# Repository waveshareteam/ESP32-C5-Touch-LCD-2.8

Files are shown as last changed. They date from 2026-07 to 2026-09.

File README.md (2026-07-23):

<div align="center">

# ESP32-C5-Touch-LCD-2.8

**2.8-inch ESP32-C5 Wi-Fi 6 touch display development board**



[中文](./README.cn.md) | English | [Product](https://www.waveshare.com/catalogsearch/result/?q=ESP32-C5-Touch-LCD-2.8) | [Documentation](https://docs.waveshare.com/ESP32-C5-Touch-LCD-2.8) | [Firmware](./Firmware/) | [ESP-IDF Examples](./example/ESP-IDF-V554/) | [Arduino Examples](./example/Arduino-v3.3.10/example/)

ESP32-C5-Touch-LCD-2.8

</div>

## Overview

ESP32-C5-Touch-LCD-2.8 is a resource package for an ESP32-C5 based 2.8-inch touch LCD development board. This repository includes Arduino examples, ESP-IDF examples, factory firmware, schematics, mechanical files, SD card demo assets, and GUI Guider UI resources for quick hardware evaluation and application development.

This package is intended for:

- Verifying ESP32-C5, LCD, touch, sensors, SD card, and audio functions.
- Building touch LCD applications with Arduino or ESP-IDF.
- Reusing BSP, LVGL examples, and GUI Guider projects for UI development.
- Checking hardware schematics, mechanical dimensions, and factory firmware resources.

## Hardware Overview

| Item | Description |
| :--- | :--- |
| MCU | ESP32-C5 |
| Display | 2.8-inch LCD, 240 x 320 resolution |
| LCD driver | ST7789 |
| Touch controller | CST3530, I2C address `0x58` |
| IO expander | CH32V003, I2C address `0x24` |
| Sensors | QMI8658 6-axis IMU, PCF85063 RTC, SHTC3 temperature and humidity sensor |
| Storage assets | Micro SD card demo assets and SPIFFS audio demo |
| UI framework | Arduino examples use LVGL v8.4.0; ESP-IDF examples use LVGL v9 |
| Hardware files | [Schematic](./schematic/ESP32-C5-Touch-LCD-2.8.pdf), [dimensions](./dimensions/ESP32-C5-Touch-LCD-2.8.pdf), [DXF](./dimensions/ESP32-C5-Touch-LCD-2.8.dxf), and [STEP](./dimensions/ESP32-C5-Touch-LCD-2.8.stp) |

> CH32V003 is used for IO expansion, LCD reset, touch reset, and backlight control. Its control firmware is pre-programmed at the factory. In normal use, only the ESP32-C5 application needs to be flashed.

## Supported Toolchains

| Development framework | Version | Examples |
| :--- | :--- | ---: |
| Arduino-ESP32 | `3.3.10` | 6 |
| ESP-IDF | `v5.5.4` | 8 |

## Hardware Resources

| Resource | Download |
| :--- | :--- |
| Schematic | [ESP32-C5-Touch-LCD-2.8.pdf](./schematic/ESP32-C5-Touch-LCD-2.8.pdf) |
| Mechanical drawing | [PDF](./dimensions/ESP32-C5-Touch-LCD-2.8.pdf) |
| 2D drawing | [DXF](./dimensions/ESP32-C5-Touch-LCD-2.8.dxf) |
| 3D model | [STEP](./dimensions/ESP32-C5-Touch-LCD-2.8.stp) |

## Repository Layout

```text
.
├── dimensions/              # Mechanical files: PDF, DXF, STEP
├── assets/                  # Product images used by the documentation
├── example/
│   ├── Arduino-v3.3.10/     # Arduino examples and bundled libraries
│   └── ESP-IDF-V554/        # ESP-IDF v5.5.4 examples
├── Firmware/                # Factory firmware
├── guider_ui/               # GUI Guider installer / UI resources
├── schematic/               # Schematic
├── sdcard/                  # SD card test files, images, and audio assets
├── LICENSE
├── README.cn.md
└── README.en.md
```

## Arduino Quick Start

Recommended environment:

- Arduino IDE
- `esp32 by Espressif Systems v3.3.10`
- Board selection: `ESP32C5 Dev Module`

Steps:

1. Install `esp32 by Espressif Systems v3.3.10` from Arduino IDE Boards Manager.
2. Select `ESP32C5 Dev Module` from `Tools` > `Board`.
3. Copy the bundled libraries to the Arduino libraries directory:

   ```text
   example/Arduino-v3.3.10/lib/lvgl
   example/Arduino-v3.3.10/lib/SensorLib
   ```

   The default Arduino library directory on Windows is usually:

   ```text
   C:\Users\<UserName>\Documents\Arduino\libraries
   ```

4. Open an `.ino` example from `example/Arduino-v3.3.10/example`, then build and flash it.
5. It is recommended to run `01_exio` first to verify the CH32V003 IO expander before testing LCD, touch, and sensor examples.

### Arduino Examples

| Example | Function |
| :--- | :--- |
| [01_exio](./example/Arduino-v3.3.10/example/01_exio/) | CH32V003 IO expander test |
| [02_I2C_qmi8658](./example/Arduino-v3.3.10/example/02_I2C_qmi8658/) | QMI8658 6-axis IMU test |
| [03_SD_Card](./example/Arduino-v3.3.10/example/03_SD_Card/) | SD card read/write test |
| [04_I2C_pcf85063](./example/Arduino-v3.3.10/example/04_I2C_pcf85063/) | PCF85063 RTC test |
| [05_shtc3](./example/Arduino-v3.3.10/example/05_shtc3/) | SHTC3 temperature and humidity sensor test |
| [06_lvgl_demo](./example/Arduino-v3.3.10/example/06_lvgl_demo/) | LCD, touch, backlight, and LVGL basic UI test |

## ESP-IDF Quick Start

Recommended environment:

- ESP-IDF v5.5.4
- Target chip: `esp32c5`

Enter any ESP-IDF example directory and run:

```powershell
idf.py set-target esp32c5
idf.py build flash monitor
```

### ESP-IDF Examples

| Example | Function |
| :--- | :--- |
| [01_ch32_test](./example/ESP-IDF-V554/01_ch32_test/) | CH32V003 IO expander test, mainly observed through serial logs |
| [02_2048](./example/ESP-IDF-V554/02_2048/) | LVGL-based 2048 touch mini game |
| [03_sd_lvgl](./example/ESP-IDF-V554/03_sd_lvgl/) | SD card text reading and LVGL display |
| [04_sd_music](./example/ESP-IDF-V554/04_sd_music/) | MP3 playback from SD card |
| [05_spiff_music](./example/ESP-IDF-V554/05_spiff_music/) | MP3 music player demo using SPIFFS assets |
| [06_wifi_weather](./example/ESP-IDF-V554/06_wifi_weather/) | Wi-Fi weather demo |
| [07_Ball_qmi](./example/ESP-IDF-V554/07_Ball_qmi/) | QMI8658 motion-controlled ball demo |
| [08_bookesia](./example/ESP-IDF-V554/08_bookesia/) | Brookesia / drawing-board style touch application demo |

## SD Card Assets

The `sdcard/` directory contains test files, images, and audio assets used by the examples. For SD-card-related demos:

- Use a Micro SD card of 64 GB or smaller.
- Format the card as FAT32.
- Copy the files from `sdcard/` to the SD card root as required by each example.
- `04_sd_music` requires a `music` folder and `.mp3` files in the SD card root.

## Factory Firmware

Current version: **V1.1**

- [Download the factory firmware](./Firmware/ESP32-C5-Touch-LCD-2.8-FactoryAppV1.1.bin)
- Refer to the [product documentation](https://docs.waveshare.com/ESP32-C5-Touch-LCD-2.8) for the verified flashing procedure and flash settings.

It can be used to restore or verify the factory demo. Before flashing it, make sure the serial port, target chip, and flash settings are correct.

## Development Notes

- For common UI changes, start from the application layer, LVGL pages, GUI Guider generated code, or example business logic.
- Avoid changing BSP, low-level drivers, pin definitions, or partition tables unless the hardware connection or board design has changed.
- If LCD or touch does not work, verify CH32V003 communication first.
- The Arduino `06_lvgl_demo` example already adapts ST7789 and CST3530, so an extra GFX display library or third-party touch library is usually not required.
- The ESP-IDF BSP has already adapted LCD, touch, backlight, audio, sensors, and CH32 IO expansion.

## Notes

- Select `ESP32C5 Dev Module` for Arduino projects.
- The Arduino example folder is designed for `esp32 by Espressif Systems v3.3.10`.
- The `ESP-IDF-V554` folder is designed for ESP-IDF v5.5.4.
- CH32V003 firmware is pre-programmed at the factory and does not need to be flashed separately.
- For the weather demo, prepare an internet-connected Wi-Fi hotspot according to the example configuration.

## License

This repository is licensed under the Apache License 2.0. See [LICENSE](./LICENSE).

## Support

For product setup, development instructions, and troubleshooting, visit the [Waveshare documentation](https://docs.waveshare.com/ESP32-C5-Touch-LCD-2.8). When reporting an issue, include the example path, framework version, reproduction steps, and complete serial log.

- [Open an issue](https://github.com/waveshareteam/ESP32-C5-Touch-LCD-2.8/issues/new)
- [Waveshare support](https://www.waveshare.com/contact_us)

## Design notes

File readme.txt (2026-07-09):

1：dimensions存放的是结构图
2：example存放的是示例程序
3：Firmware存放的是出厂固件测试地址
4：guider_ui存放的是基于Guider工具做的ui源码，方便您后续的二次开发
5：schematic存放的是原理图
6：sdcard文件夹里面放的是music和photo

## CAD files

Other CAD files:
dimensions/ESP32-C5-Touch-LCD-2.8.stp
dimensions/ESP32-C5-Touch-LCD-2.8.dxf

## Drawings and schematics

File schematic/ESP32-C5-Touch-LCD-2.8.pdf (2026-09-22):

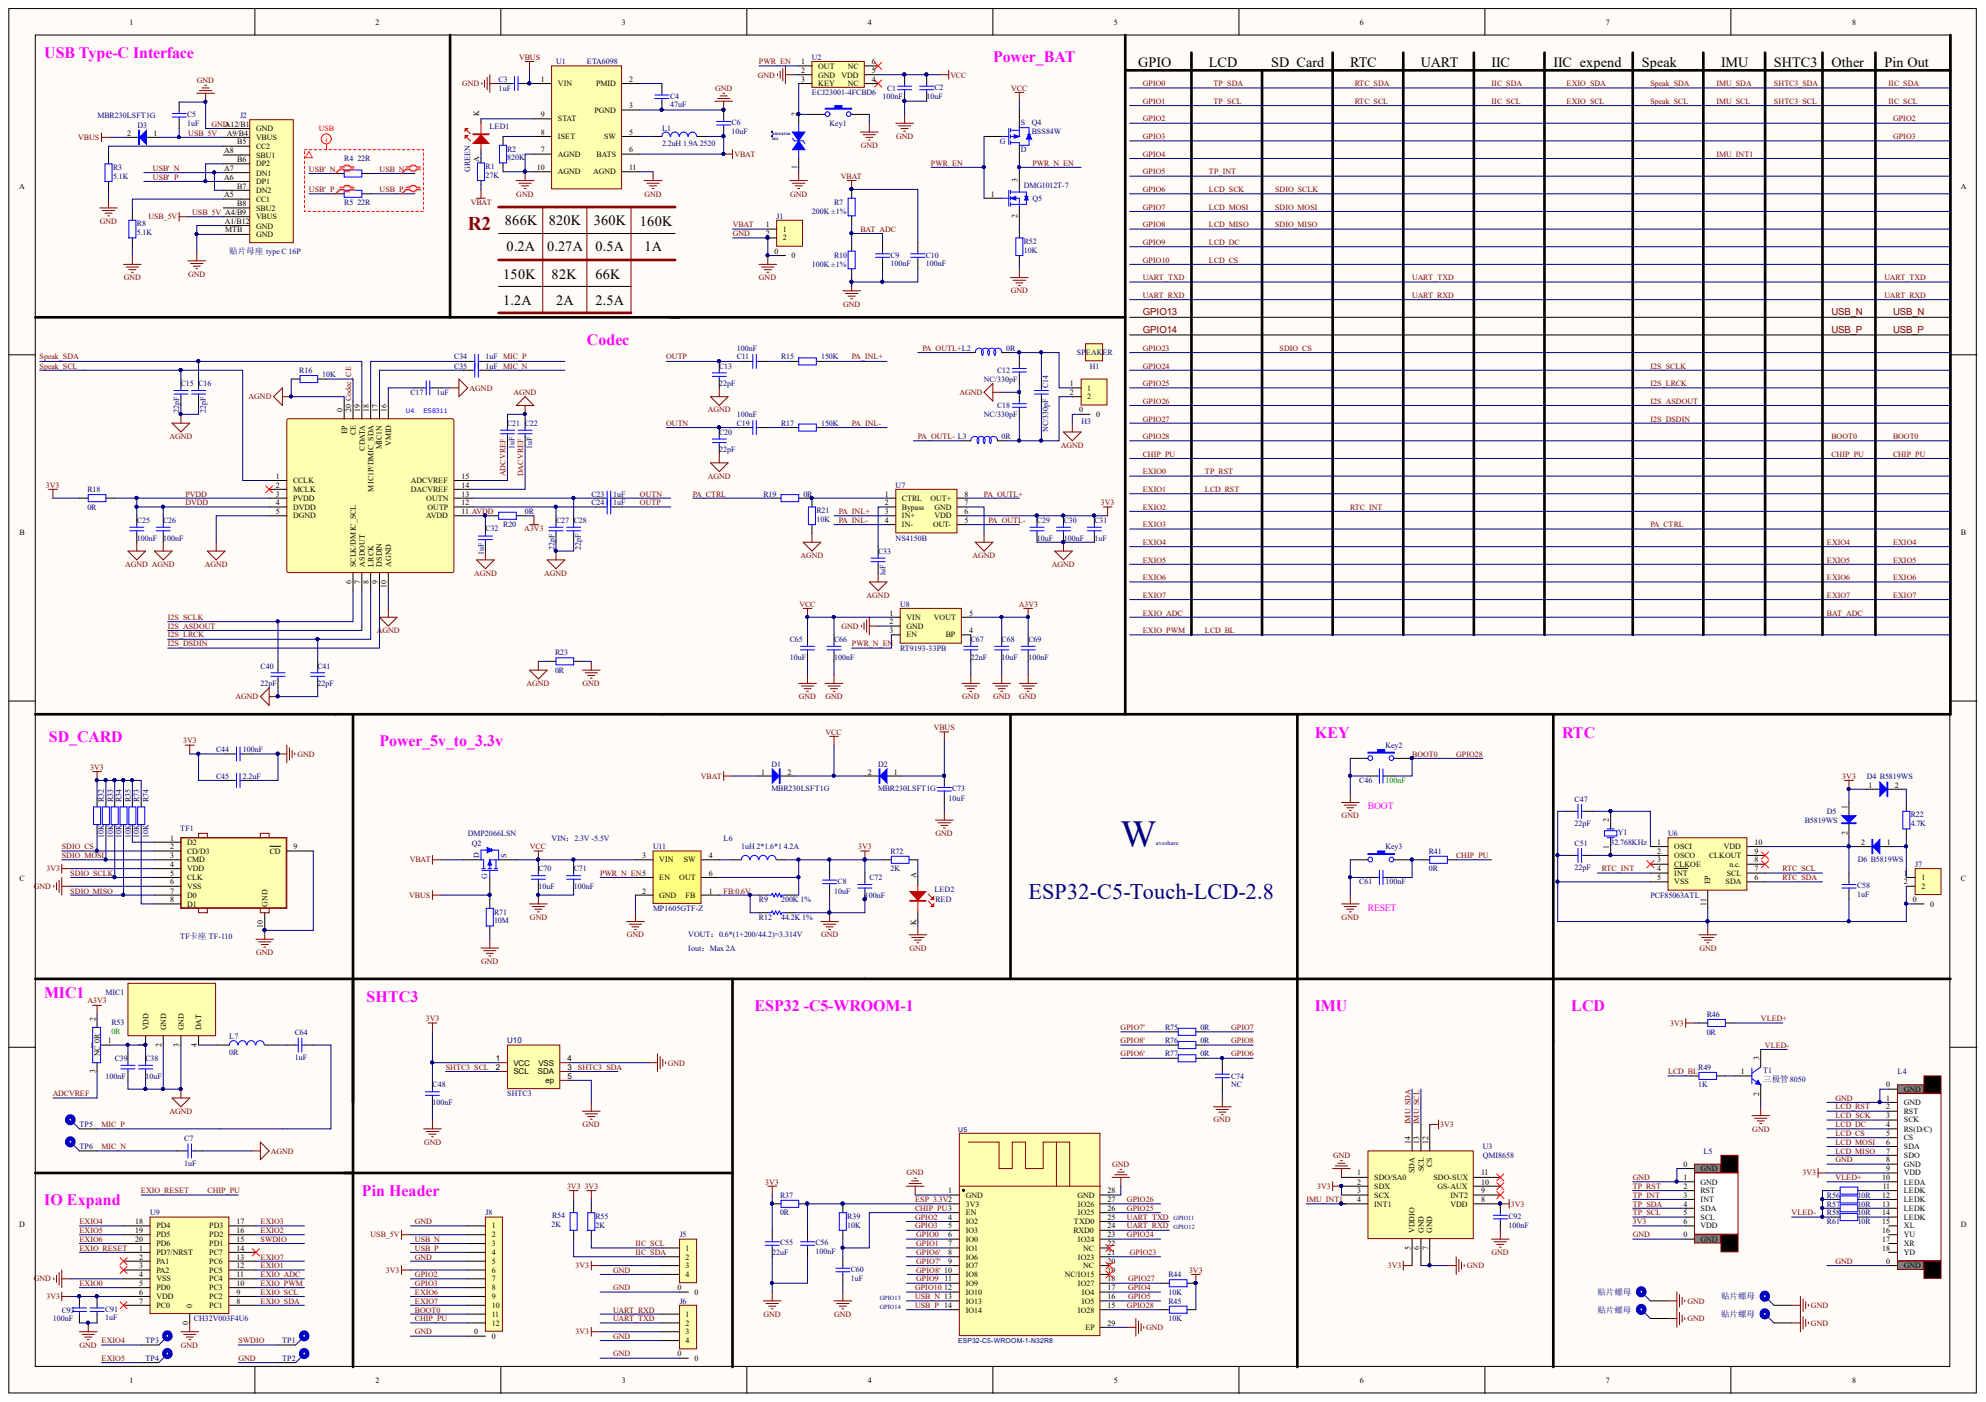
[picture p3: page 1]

GPIO13 GPIO14 | | | USB_N USB_P | USB_N USB_P

GPIO23 | SDIO_CS

GPIO24 | | I2S_SCLK

GPIO25 | | I2S_LRCK

GPIO26 | | I2S_ASDOUT

VMID 16 MIC1N 17 MIC1P/DMIC_SDA 18 CDATA 19 CE 20 EP 0

GPIO27 | | I2S_DSDIN

CHIP_PU | | CHIP_PU | CHIP_PU

EXIO0 | TP_RST

EXIO1 | LCD_RST

EXIO5 | EXIO5 | EXIO5

EXIO6 | EXIO6 | EXIO6

EXIO7 | EXIO7 | EXIO7

EXIO_ADC | BAT_ADC

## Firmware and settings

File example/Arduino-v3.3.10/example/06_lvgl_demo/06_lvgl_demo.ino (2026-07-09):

#include <Arduino.h>
#define LV_CONF_INCLUDE_SIMPLE
#include <lvgl.h>
#include <esp_heap_caps.h>

#include "Board_IO.h"
#include "Display_ST7789.h"
#include "Touch_CST3530.h"

#if LV_COLOR_DEPTH != 16
#error "This example requires LV_COLOR_DEPTH 16."
#endif

#if LV_COLOR_16_SWAP != 0
#error "This example follows the ST7789 reference project and passes LVGL RGB565 data directly. Keep LV_COLOR_16_SWAP 0."
#endif

static constexpr int LCD_DRAW_BUF_HEIGHT = 40;

static bool touch_ready = false;
static lv_disp_draw_buf_t draw_buf;
static lv_color_t *draw_buf_1 = nullptr;
static lv_color_t *draw_buf_2 = nullptr;
static lv_disp_drv_t disp_drv;
static lv_indev_drv_t indev_drv;
static lv_obj_t *touch_label = nullptr;
static lv_obj_t *brightness_label = nullptr;

static void display_flush(lv_disp_drv_t *drv, const lv_area_t *area, lv_color_t *color_p)
{
  LCD_addWindow(area->x1, area->y1, area->x2, area->y2, (uint16_t *)&color_p->full);
  lv_disp_flush_ready(drv);
}

static void touch_read(lv_indev_drv_t *drv, lv_indev_data_t *data)
{
  (void)drv;

  uint16_t touchpad_x[CST3530_LCD_TOUCH_MAX_POINTS] = {0};
  uint16_t touchpad_y[CST3530_LCD_TOUCH_MAX_POINTS] = {0};
  uint16_t strength[CST3530_LCD_TOUCH_MAX_POINTS] = {0};
  uint8_t touchpad_cnt = 0;

  if (touch_ready) {
    Touch2_Read_Data();
    uint8_t pressed = Touch2_Get_XY(touchpad_x, touchpad_y, strength, &touchpad_cnt, CST3530_LCD_TOUCH_MAX_POINTS);

    if (pressed && touchpad_cnt > 0) {
      if (touchpad_x[0] >= LCD_WIDTH) {
        touchpad_x[0] = LCD_WIDTH - 1;
      }
      if (touchpad_y[0] >= LCD_HEIGHT) {
        touchpad_y[0] = LCD_HEIGHT - 1;
      }

      data->point.x = touchpad_x[0];
      data->point.y = touchpad_y[0];
      data->state = LV_INDEV_STATE_PR;

      if (touch_label != nullptr) {
        lv_label_set_text_fmt(touch_label, "Touch: %u, %u", touchpad_x[0], touchpad_y[0]);
      }
      return;
    }
  }

  data->state = LV_INDEV_STATE_REL;
}

static void brightness_slider_event_cb(lv_event_t *e)
{
  lv_obj_t *slider = lv_event_get_target(e);
  int32_t brightness = lv_slider_get_value(slider);

  Set_Backlight((uint8_t)brightness);

  if (brightness_label != nullptr) {
    lv_label_set_text_fmt(brightness_label, "Backlight %ld%%", (long)brightness);
  }
}

static void create_demo_ui()
{
  lv_obj_t *scr = lv_scr_act();
  lv_obj_set_style_bg_color(scr, lv_color_hex(0x101820), 0);
  lv_obj_set_style_bg_grad_color(scr, lv_color_hex(0x1D3557), 0);
  lv_obj_set_style_bg_grad_dir(scr, LV_GRAD_DIR_VER, 0);

  lv_obj_t *title = lv_label_create(scr);
  lv_label_set_text(title, "ESP32-C5 Touch LCD 2.8");
  lv_obj_set_style_text_color(title, lv_color_white(), 0);
  lv_obj_align(title, LV_ALIGN_TOP_MID, 0, 28);

  lv_obj_t *subtitle = lv_label_create(scr);
  lv_label_set_text(subtitle, "Arduino + ST7789 + CST3530");
  lv_obj_set_style_text_color(subtitle, lv_color_hex(0xA8DADC), 0);
  lv_obj_align(subtitle, LV_ALIGN_TOP_MID, 0, 62);

  lv_obj_t *panel = lv_obj_create(scr);
  lv_obj_set_size(panel, 220, 142);
  lv_obj_align(panel, LV_ALIGN_CENTER, 0, 8);
  lv_obj_set_style_radius(panel, 8, 0);
  lv_obj_set_style_bg_color(panel, lv_color_hex(0xF1FAEE), 0);
  lv_obj_set_style_border_width(panel, 0, 0);
  lv_obj_set_style_shadow_width(panel, 14, 0);
  lv_obj_set_style_shadow_opa(panel, LV_OPA_30, 0);

  lv_obj_t *status = lv_label_create(panel);
  lv_label_set_text(status, "Display OK");
  lv_obj_set_style_text_color(status, lv_color_hex(0x1D3557), 0);
  lv_obj_align(status, LV_ALIGN_TOP_MID, 0, 14);

  touch_label = lv_label_create(panel);
  lv_label_set_text(touch_label, touch_ready ? "Touch: ready" : "Touch: not found");
  lv_obj_set_style_text_color(touch_label, lv_color_hex(0x457B9D), 0);
  lv_obj_align(touch_label, LV_ALIGN_CENTER, 0, -8);

  lv_obj_t *button = lv_btn_create(panel);
  lv_obj_set_size(button, 92, 30);
  lv_obj_align(button, LV_ALIGN_BOTTOM_MID, 0, -8);

  lv_obj_t *button_label = lv_label_create(button);
  lv_label_set_text(button_label, "Touch");
  lv_obj_center(button_label);

  brightness_label = lv_label_create(scr);
  lv_label_set_text(brightness_label, "Backlight 100%");
  lv_obj_set_style_text_color(brightness_label, lv_color_white(), 0);
  lv_obj_align(brightness_label, LV_ALIGN_BOTTOM_MID, 0, -48);

  lv_obj_t *brightness_slider = lv_slider_create(scr);
  lv_obj_set_size(brightness_slider, 208, 16);
  lv_slider_set_range(brightness_slider, 5, 100);
  lv_slider_set_value(brightness_slider, 100, LV_ANIM_OFF);
  lv_obj_align(brightness_slider, LV_ALIGN_BOTTOM_MID, 0, -24);
  lv_obj_add_event_cb(brightness_slider, brightness_slider_event_cb, LV_EVENT_VALUE_CHANGED, NULL);
  lv_obj_set_style_bg_color(brightness_slider, lv_color_hex(0x324A5F), LV_PART_MAIN);
  lv_obj_set_style_bg_opa(brightness_slider, LV_OPA_COVER, LV_PART_MAIN);
  lv_obj_set_style_bg_color(brightness_slider, lv_color_hex(0x2A9D8F), LV_PART_INDICATOR);
  lv_obj_set_style_bg_color(brightness_slider, lv_color_hex(0xF1FAEE), LV_PART_KNOB);
  lv_obj_set_style_pad_all(brightness_slider, 2, LV_PART_KNOB);
}

void setup()
{
  Serial.begin(115200);
  delay(200);
  Serial.println();
  Serial.println("ESP32-C5-Touch-LCD-2.8 Arduino LVGL demo");

  if (!Board_IO_Init(Wire)) {
    Serial.println("CH32V003 IO expander init failed");
  }

  LCD_Init();
  Backlight_Init();
  touch_ready = TOUCH2_Init();

  lv_init();

  const uint32_t buf_pixels = LCD_WIDTH * LCD_DRAW_BUF_HEIGHT;
  draw_buf_1 = static_cast<lv_color_t *>(heap_caps_malloc(buf_pixels * sizeof(lv_color_t), MALLOC_CAP_INTERNAL | MALLOC_CAP_8BIT));
  draw_buf_2 = static_cast<lv_color_t *>(heap_caps_malloc(buf_pixels * sizeof(lv_color_t), MALLOC_CAP_INTERNAL | MALLOC_CAP_8BIT));
  if (!draw_buf_1 || !draw_buf_2) {
    draw_buf_1 = static_cast<lv_color_t *>(heap_caps_malloc(buf_pixels * sizeof(lv_color_t), MALLOC_CAP_8BIT));
    draw_buf_2 = static_cast<lv_color_t *>(heap_caps_malloc(buf_pixels * sizeof(lv_color_t), MALLOC_CAP_8BIT));
  }

  if (!draw_buf_1 || !draw_buf_2) {
    Serial.println("LVGL draw buffer allocation failed");
    while (true) {
      delay(1000);
    }
  }

  lv_disp_draw_buf_init(&draw_buf, draw_buf_1, draw_buf_2, buf_pixels);

  lv_disp_drv_init(&disp_drv);
  disp_drv.hor_res = LCD_WIDTH;
  disp_drv.ver_res = LCD_HEIGHT;
  disp_drv.flush_cb = display_flush;
  disp_drv.draw_buf = &draw_buf;
  lv_disp_drv_register(&disp_drv);

  if (touch_ready) {
    lv_indev_drv_init(&indev_drv);
    indev_drv.type = LV_INDEV_TYPE_POINTER;
    indev_drv.read_cb = touch_read;
    lv_indev_drv_register(&indev_drv);
  }

  create_demo_ui();
  Serial.println("LVGL demo started");
}

void loop()
{
  lv_tick_inc(5);
  lv_timer_handler();

  delay(5);
}

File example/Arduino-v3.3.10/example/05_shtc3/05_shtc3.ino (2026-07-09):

#include <Arduino.h>
#include <Wire.h>

// ESP32-C5-Touch-LCD-2.8 BSP: SCL = GPIO1, SDA = GPIO0
static constexpr uint8_t I2C_SDA = 0;
static constexpr uint8_t I2C_SCL = 1;
static constexpr uint32_t I2C_FREQ = 400000;

static constexpr uint8_t SHTC3_ADDR = 0x70;
static constexpr uint16_t SHTC3_CMD_WAKE = 0x3517;
static constexpr uint16_t SHTC3_CMD_SLEEP = 0xB098;
static constexpr uint16_t SHTC3_CMD_SOFT_RESET = 0x805D;
static constexpr uint16_t SHTC3_CMD_READ_ID = 0xEFC8;
static constexpr uint16_t SHTC3_CMD_MEASURE_T_RH = 0x7866; // T first, no clock stretching, normal mode

static uint8_t shtc3Crc(const uint8_t *data, size_t len)
{
  uint8_t crc = 0xFF;

  for (size_t i = 0; i < len; i++) {
    crc ^= data[i];
    for (uint8_t bit = 0; bit < 8; bit++) {
      crc = (crc & 0x80) ? (crc << 1) ^ 0x31 : (crc << 1);
    }
  }

  return crc;
}

static bool writeCommand(uint16_t cmd)
{
  Wire.beginTransmission(SHTC3_ADDR);
  Wire.write(cmd >> 8);
  Wire.write(cmd & 0xFF);
  return Wire.endTransmission() == 0;
}

static bool wakeShtc3()
{
  if (!writeCommand(SHTC3_CMD_WAKE)) {
    return false;
  }

  delayMicroseconds(240);
  return true;
}

static void sleepShtc3()
{
  writeCommand(SHTC3_CMD_SLEEP);
}

static bool readWordWithCrc(uint16_t *value)
{
  uint8_t buf[3] = {0};

  if (Wire.requestFrom(SHTC3_ADDR, static_cast<uint8_t>(3)) != 3) {
    return false;
  }

  for (uint8_t i = 0; i < sizeof(buf); i++) {
    buf[i] = Wire.read();
  }

  if (shtc3Crc(buf, 2) != buf[2]) {
    return false;
  }

  *value = (static_cast<uint16_t>(buf[0]) << 8) | buf[1];
  return true;
}

static bool readShtc3Id(uint16_t *id)
{
  if (!wakeShtc3()) {
    return false;
  }

  bool ok = writeCommand(SHTC3_CMD_READ_ID) && readWordWithCrc(id);
  sleepShtc3();
  return ok;
}

static bool readShtc3(float *temperature, float *humidity)
{
  uint8_t buf[6] = {0};

  if (!wakeShtc3()) {
    return false;
  }

  if (!writeCommand(SHTC3_CMD_MEASURE_T_RH)) {
    sleepShtc3();
    return false;
  }

  delay(20);

  if (Wire.requestFrom(SHTC3_ADDR, static_cast<uint8_t>(6)) != 6) {
    sleepShtc3();
    return false;
  }

  for (uint8_t i = 0; i < sizeof(buf); i++) {
    buf[i] = Wire.read();
  }

  sleepShtc3();

  if (shtc3Crc(&buf[0], 2) != buf[2] || shtc3Crc(&buf[3], 2) != buf[5]) {
    return false;
  }

  uint16_t rawTemp = (static_cast<uint16_t>(buf[0]) << 8) | buf[1];
  uint16_t rawHumidity = (static_cast<uint16_t>(buf[3]) << 8) | buf[4];

  *temperature = -45.0f + 175.0f * rawTemp / 65535.0f;
  *humidity = 100.0f * rawHumidity / 65535.0f;
  return true;
}

void setup()
{
  Serial.begin(115200);
  delay(1000);

  Serial.println();
  Serial.println("SHTC3 test");

  Wire.begin(I2C_SDA, I2C_SCL);
  Wire.setClock(I2C_FREQ);

  if (!wakeShtc3()) {
    Serial.println("SHTC3 not found. Check SDA/SCL and power.");
    return;
  }

  writeCommand(SHTC3_CMD_SOFT_RESET);
  delay(2);

  uint16_t id = 0;
  if (readShtc3Id(&id)) {
    Serial.printf("SHTC3 ID: 0x%04X\r\n", id);
  } else {
    Serial.println("SHTC3 ID read failed, continue measuring...");
  }
}

void loop()
{
  float temperature = 0.0f;
  float humidity = 0.0f;

  if (readShtc3(&temperature, &humidity)) {
    Serial.printf("Temperature: %.2f C, Humidity: %.2f %%\r\n", temperature, humidity);
  } else {
    Serial.println("Failed to read SHTC3");
  }

  delay(1000);
}

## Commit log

2026-09-22 Remove Git LFS tracking
    [ESP32-C5-Touch-LCD-2.8.dxf]
2026-10-13 Modernize example layout and add framework CI
2026-10-13 Fix QMI8658 header include case for Linux builds
2026-10-22 fix(bsp): share audio resources and reserve LCD DMA buffers
    Port factory audio lifecycle, microphone and amplifier interfaces while retaining schematic pin routing, touch bus context and display byte order.
2026-10-22 chore(arduino): trim bundled libraries after build comparison
    Remove 960 non-build files while retaining sources and licenses. Bundled files: 1653 to 693; bytes: 204615817 to 97253585. All six Arduino 3.3.12 sketches retain identical Flash and RAM usage.
2026-10-23 feat(factory): include rebuilt apps and board interfaces
2026-10-24 feat(arduino): share board drivers and add battery voltage example
2026-10-24 fix(bsp): wait for display lock before showing initial frame
2026-10-26 fix(examples): select ESP32-C5 by default
2026-10-26 fix(build): pin tested display adapter and SDK range
2026-10-26 fix(arduino): wait for IO expander before enabling battery display
